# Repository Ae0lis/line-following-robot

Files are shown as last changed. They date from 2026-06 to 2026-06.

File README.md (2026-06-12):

# Autonomous Line-Following Robot

A custom-PCB line-following robot built for the EE 201 capstone at the University
of Washington. This was a one-month competition to design the fastest,
most accurate line follower in the class.

**Full writeup:** https://ae0lis.github.io/projects/line_robot/

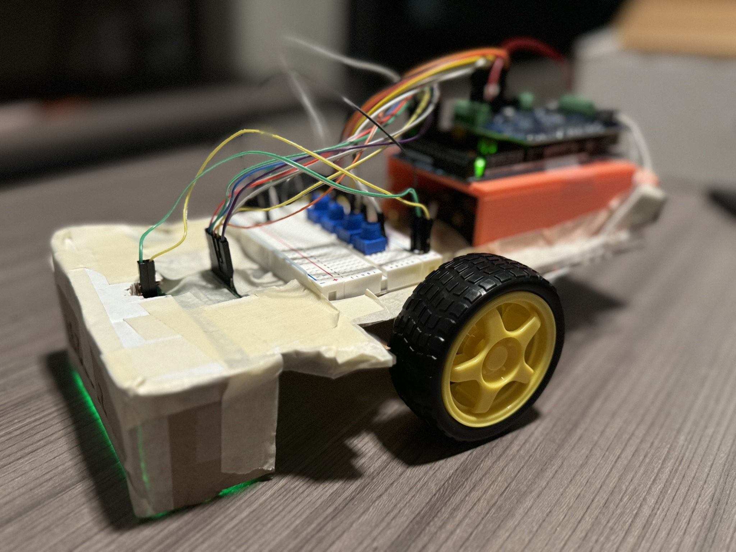
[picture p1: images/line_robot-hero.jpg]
The finished robot


## Overview

The robot follows a black line on a light surface using a custom seven-channel
photoresistor array, processes the readings through a PID controller on an Arduino,
and steers by driving its two motors at differing speeds. Built by a three-person
team over one month; completed the full competition track.

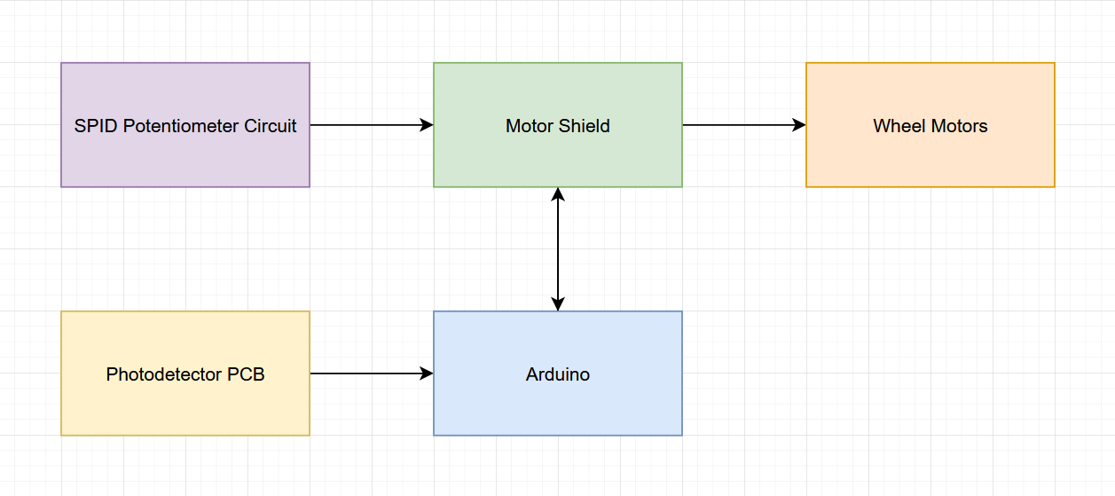
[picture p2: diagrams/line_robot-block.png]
Block diagram


## Repository structure

| Path | Contents |
|---|---|
| `kicad/` | KiCad project — schematic, board layout, and netlist for the sensor array |
| `kicad/PCB_share/` | Gerber + drill files for fabrication (open in any Gerber viewer, no KiCad needed) |
| `firmware/` | Arduino control code (see note below) |
| `renders/` | Exported schematic and 3D board renders |
| `images/` | Photos of the assembled robot |
| `diagrams/` | Diagrams for explaining the robot's systems |

## The sensor board

The core of the project is a custom PCB I designed and laid out in KiCad:

- **Seven-channel photoresistor array** — each channel pairs a photoresistor with an
  LED, flooding the surface with consistent light so a change in reading reflects
  floor color rather than ambient light or shadow.
- **Per-LED current limiting** — each LED has its own 1 kΩ resistor.
- **Copper pours** for GND and VCC instead of hand-routed power traces, which helped
  keep the board compact (40 × 80 mm between mounting holes).
- **Sensor outputs map to Arduino analog pins A8–A14**, matching the firmware.

## Firmware

The control firmware is based on PID scaffolding provided to all teams in the course.
My contribution here was mapping the controller to this board's pin assignments,
configuring it, and tuning the PID constants against the competition track. Both
files are included for transparency:

- `10_5_line_follower_code_template.ino` — the course-provided starting point
- `10_5_line_follower_code_completed.ino` — the filled-in, tuned version used in the robot

Tuned constants at competition: S 30, P 24, I 0, D 24.
Calibrated sensor readings: ~2500 on black, ~1000 on white.

## Viewing the board

- **Renders:** the PNGs in `renders/` show the schematic and 3D board.
- **Gerbers:** open `kicad/PCB_share/` in any Gerber viewer to inspect the manufacturing layers.
- **Source:** open `kicad/Final_Project_PCB.kicad_pro` in KiCad 9.0 or newer. 
			  May work on older versions, but no promises!

## Team

Built by Dat Ly, Michael Zhang, and Ben Robison for EE 201 (University of Washington).
I (Ben) was responsible for the sensor PCB, firmware configuration and tuning, and much of
the physical assembly.

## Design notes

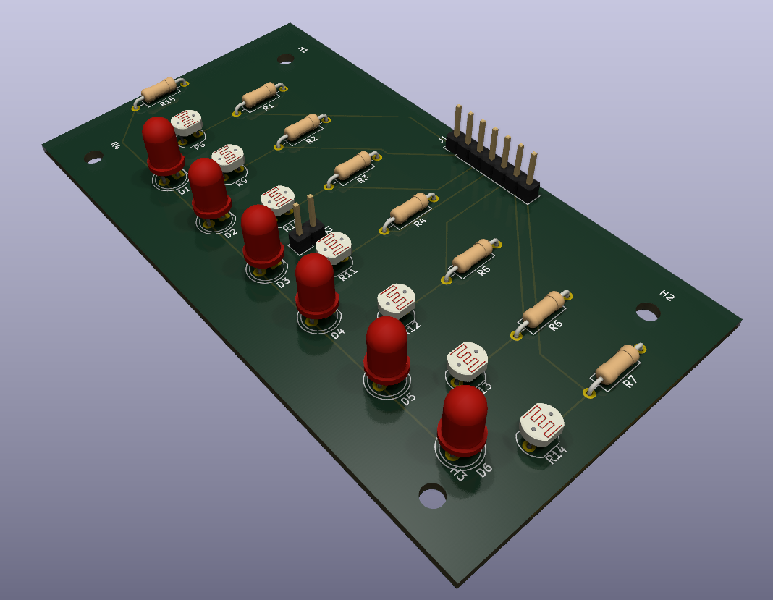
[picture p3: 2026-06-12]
renders/line_robot-pcb.png

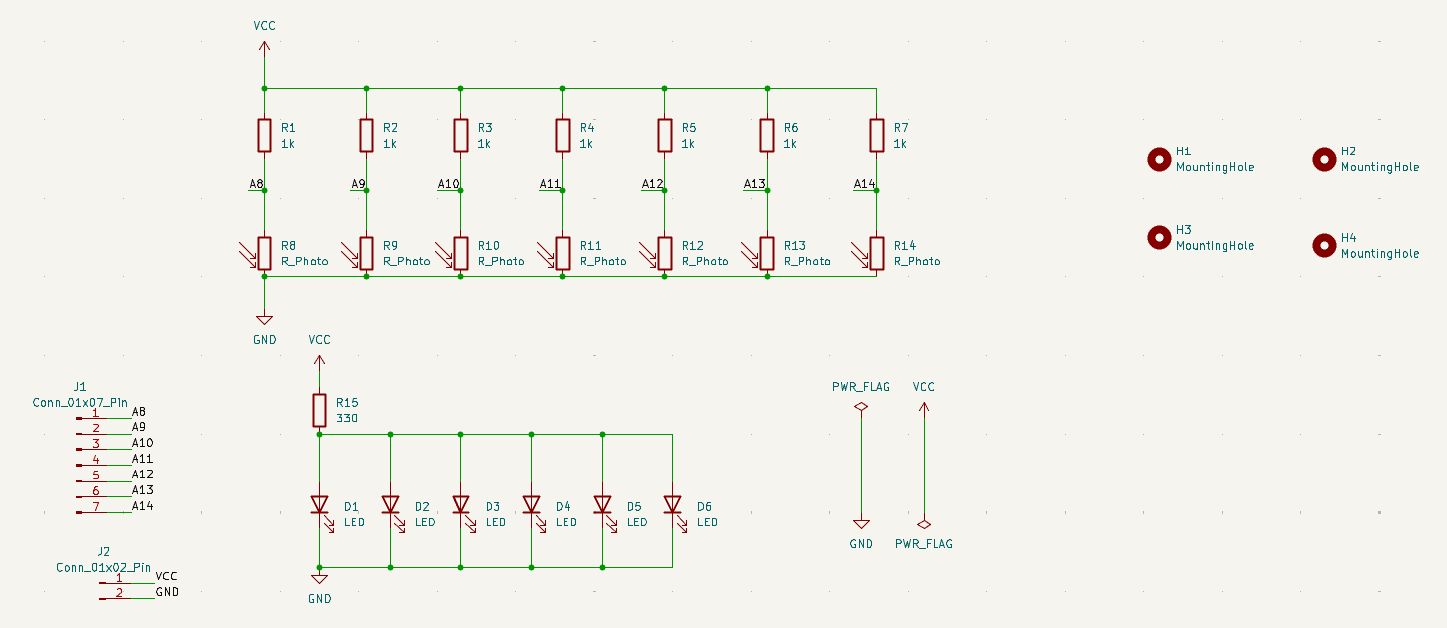
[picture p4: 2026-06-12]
renders/line_robot-sch.png

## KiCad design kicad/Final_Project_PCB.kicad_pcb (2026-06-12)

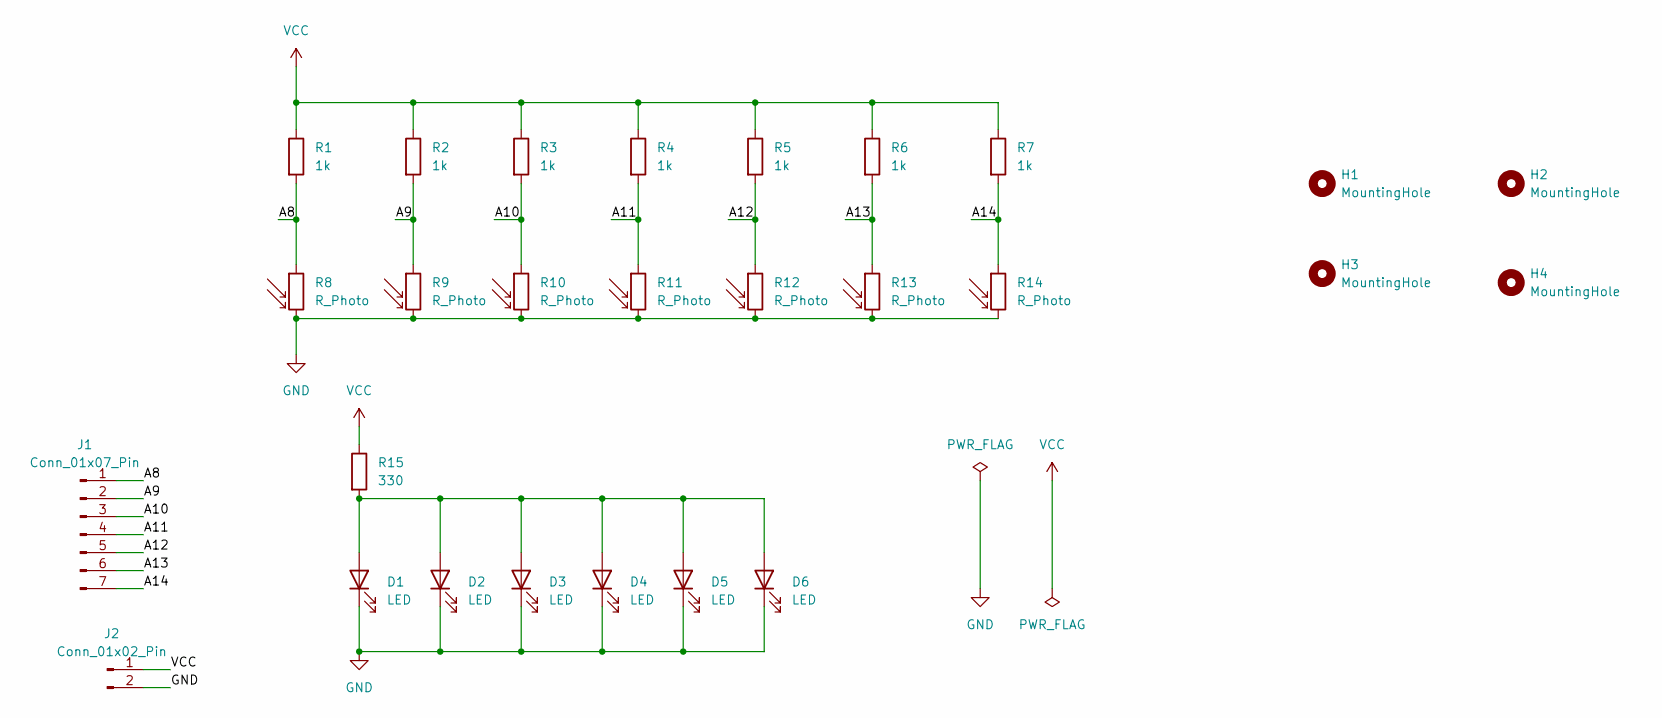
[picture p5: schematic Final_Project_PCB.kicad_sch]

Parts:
D1, D2, D3, D4, D5, D6: LED; LED_D5.0mm
H1, H2, H3, H4: MountingHole; MountingHole_3.2mm_M3
J1: Conn_01x07_Pin; PinHeader_1x07_P2.54mm_Vertical
J2: Conn_01x02_Pin; PinHeader_1x02_P2.54mm_Vertical
R1, R2, R3, R4, R5, R6, R7: 1k; R_Axial_DIN0207_L6.3mm_D2.5mm_P10.16mm_Horizontal
R8, R9, R10, R11, R12, R13, R14: R_Photo; R_LDR_5.0x4.1mm_P3mm_Vertical
R15: 330; R_Axial_DIN0207_L6.3mm_D2.5mm_P10.16mm_Horizontal

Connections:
/A8: J1.1, R1.2, R8.1
/A9: J1.2, R2.2, R9.1
/A10: J1.3, R3.2, R10.1
/A11: J1.4, R4.2, R11.1
/A12: J1.5, R5.2, R12.1
/A13: J1.6, R6.2, R13.1
/A14: J1.7, R7.2, R14.1
GND: D1.1 (K), D2.1 (K), D3.1 (K), D4.1 (K), D5.1 (K), D6.1 (K), J2.2, R8.2, R9.2, R10.2, R11.2, R12.2, R13.2, R14.2
unnamed: D1.2 (A), D2.2 (A), D3.2 (A), D4.2 (A), D5.2 (A), D6.2 (A), R15.2
VCC: J2.1, R1.1, R2.1, R3.1, R4.1, R5.1, R6.1, R7.1, R15.1

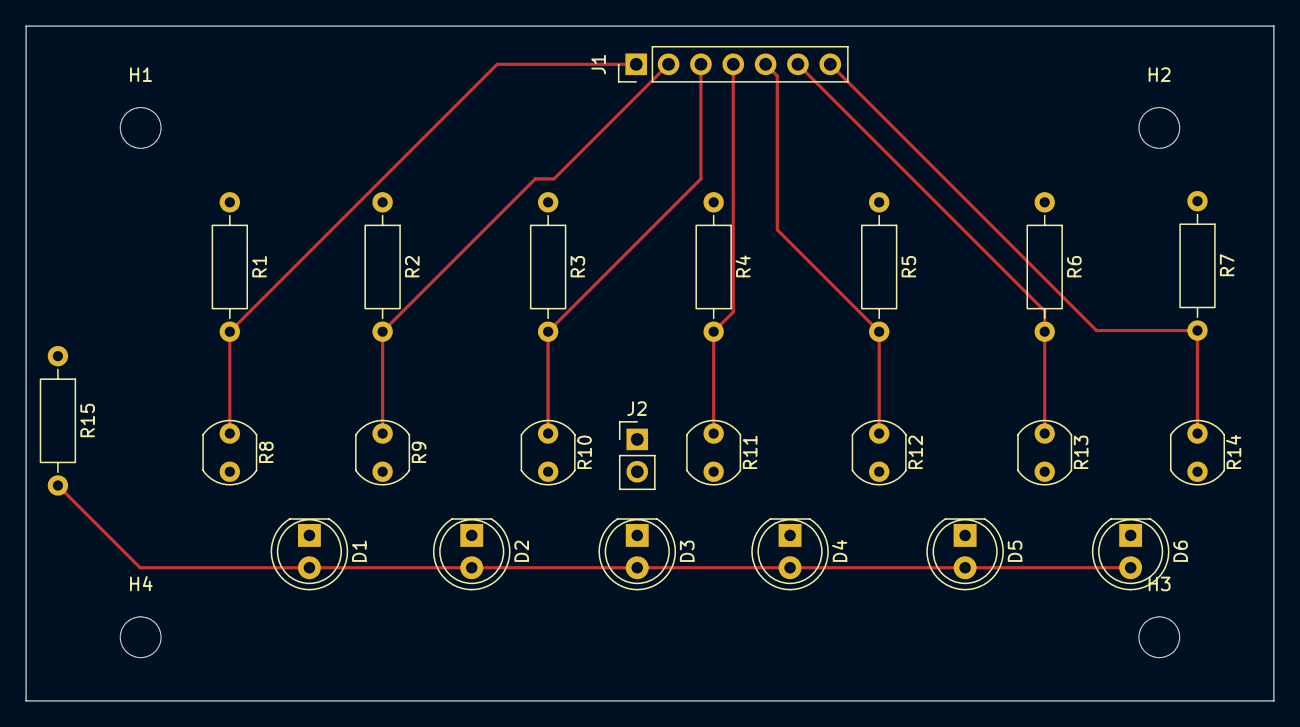
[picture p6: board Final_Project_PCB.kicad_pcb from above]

Board: 2 copper layers, 98.0 x 53.0 mm, 27 parts (0 on the bottom side), 10 nets.

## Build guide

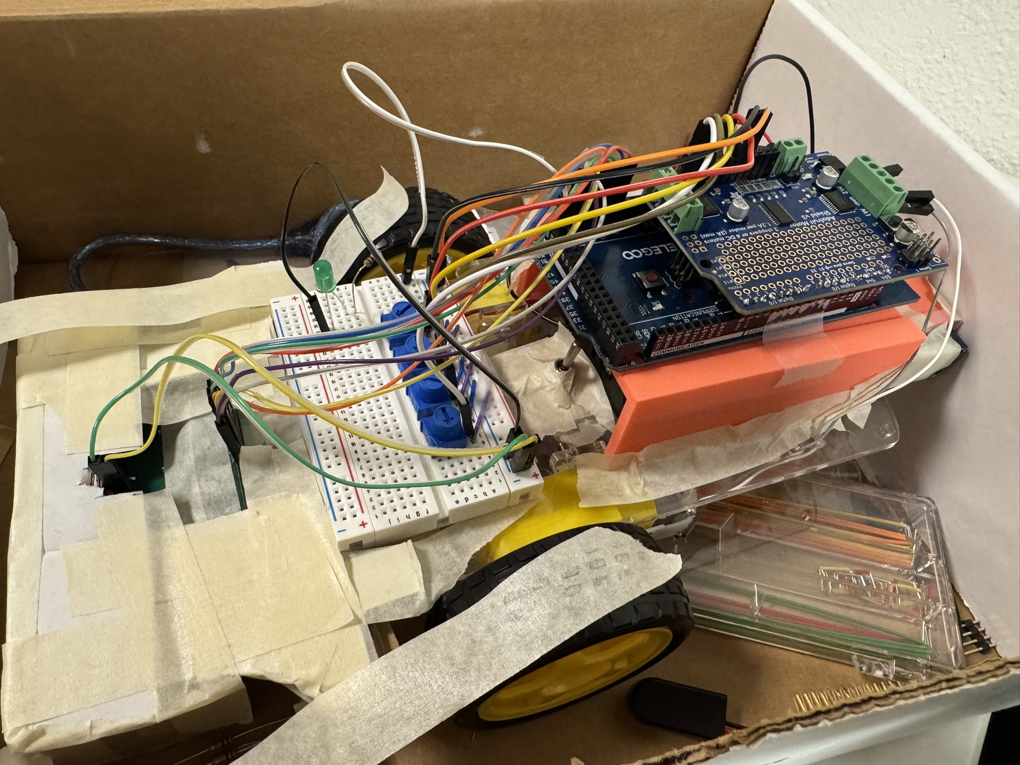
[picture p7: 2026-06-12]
images/line_robot-assembly.jpg

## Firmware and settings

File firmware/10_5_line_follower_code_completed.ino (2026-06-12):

/* ************************************************************************************************* */
// * ECE 201: Line Following Robot with PID * //
/* ************************************************************************************************* */
// This is code for your PID controlled line following robot. 
//
// Code Table of Contents
  // 1) Declare Variables - declares many variables as global variables so each variable can be accessed from every function
  // 2) Setup (Main) - runs once at beginning when you press button on arduino or motor drive or when you open serial monitor
  // 3) Loop (Main) - loops forever calling on a series of functions 
  // 4) Blink - blinks and LED
  // 5) Calibration - makes white = 0 and black = 100 (a few seconds to prep, a few seconds on white, a few seconds to move to black, a few seconds of black)
  // 6) Read Potentiometers - reads each potentiometer
  // 7) Run Motors - runs motors
  // 8) Read Photoresistors - reads each photoresistor
  // 9) Calculate Error - calculate error from photoresistor readings
  // 10) PID Turn - takes the error and implements PID control
  // 11) Print - used for debugging but can comment out when not debugging because it slows down program

// ************************************************************************************************* //
// Declare Variables

// Variables and Libaries for Motor
#include <Wire.h>
#include <Adafruit_MotorShield.h> // Must add libary - see MotorShield Manual
//https://cdn-learn.adafruit.com/downloads/pdf/adafruit-motor-shield-v2-for-arduino.pdf

Adafruit_MotorShield AFMS = Adafruit_MotorShield();
// Motors can be switched here (1) <--> (2)
Adafruit_DCMotor *Motor1 = AFMS.getMotor(1); // left motor
Adafruit_DCMotor *Motor2 = AFMS.getMotor(2); // right motor
  
// Set Initial Speed of Motors (CAN BE EDITED BY USER)
// TODO: Replace "___", and set the default motor speeds to an integer between 0 and 255.
//  the defualt motor speed is how fast the cart will move with no inputs. this can be
//  thought of as how fast should the cart be going when travelling in a straight line.
//  theoretical max. is 255, but the motors will likely overdraw power and cause the Arduino to shut off. 
//  motors likely need a minimum speed of at least 30 to move the cart.
//  a good starting speed is roughly 50-60. motor speeds are separated incase one motor turns faster than the other.  
const int M1Sp = ___; 
const int M2Sp = ___;

// Variables for Potentiometer
// TODO: Replace "___", and assign the pin number connected to the Arduino
const int S_pin = ___; //proportional control
const int P_pin = ___; //proportional control
const int I_pin = ___; //integral control
const int D_pin = ___; //derivative control

// User set SPID values
// TODO: Replace "___", and assign an integer value for the MAX value of S, P, I, and D.
//  The on-cart potentiometers are used to determine the actual values of S, P, I, and D. 
//  Note: These values will likely need to be experimentally determined
const float speed       = ___;
const float proportion  = ___;
const float integral    = ___;
const float derivative  = ___;

const int numMeas = ___; // TODO: Replace "___", and assign number of calibration measurements
                         //   setting numMeas to 40 as in code 10.4 is recommended

// Initialize SPID values to zero
int SpRead = 0; //Speed Increase 
int kPRead = 0; //proportional gain
int kIRead = 0; //integral gain
int kDRead = 0; //derivative gain
  
// Variables for Light Sensors (arrays are used to simplify the code):
//  these are variables that have multiple elements to each variable name.
//  LDR_Pin holds 7 values of the LDR pin connection to the Arduino
// TODO: Replace "___", and assign the pin number for each LDR connected to the Arduino.
//  reference 10.2 potentiometer code if necessarry
int LDR_Pin[7] = {___,
                  ___,
                  ___,
                  ___,
                  ___,
                  ___,
                  ___}; 
int LDR[7]; // this is an empty array that will hold the readings from our potentiometers

// TODO: Replace "___", and assign the pin number connected to the Arduino.
//  it is recommended to use the built-in LED connected to pin 13, but can change 
//  to another digital pin and connect external LED to be more easily seen
int led_Pin = ___; 

// Calibration Variables
//  Complete understanding of the calibration process is not required 
float Mn[7]; // array containing minimum read values of every potentiometer
float Mx[7]; // array containing maximum read values of every potentiometer
float LDRf[7] = {0.,0.,0.,0.,0.,0.,0.}; // initialize the LDR read values to float zero

int MxRead; // maximum read value by any potentiometer
int MxIndex; // index (location in array) of max read value
float AveRead; // average read value of potentiometer
int CriteriaForMax; // value to determine whether a read value is a max
float WeightedAve; // weighted average after calibration
  
// Error calculation variables
int im0, im1, im2; 
  
// Motor control variables
int M1SpeedtoMotor, M2SpeedtoMotor; // actual speeds motor will be rotating at
int Turn; // which direction and how sharply should the cart turn
int M1P = 0, M2P = 0; // proportion control for motors 1 and 2 respectively
float error; // current error
int lasterror = 0; // previous error
int sumerror = 0; // sum of total errors
float kP, kI, kD; // final values of P, I, and D used in control
 
// ************************************************************************************************* //
// setup - runs once
void setup() {
  Serial.begin(___); // TODO: Replace "___", and input the baud rate for serial communication
  AFMS.begin(); // initialize the motor

  pinMode(___, ___); // TODO: Replace "___", and set the led_pin to be an output
  
  Calibrate(); // Calibrate black and white sensing
  
  ReadPotentiometers(); // Read potentiometer values (Sp, P, I, & D)
  
  delay(2000); // Delay to ensure cart is properly placed before moving
  
  RunMotors(); // Starts motors straight forward depending on Sp (Speed from potentiometer) and M1Sp/M2Sp (Nominal values)
 
} // end setup()

// ************************************************************************************************* //
// loop - runs/loops forever
void loop() {
  // Note: some functions are only helpful for debugging and can be commented out once functionality is ensured
 
  ReadPotentiometers(); // Only if you want to see Potentiometers working in set up as you run the line following
  
  ReadPhotoResistors(); // Read photoresistors and map to 0-100 based on calibration
  
  CalcError();
  
  PID_Turn(); // PID Control and Output to motors to turn
  RunMotors(); // Uses info from
  
  Print(); // Print values to serial monitor //currently commented out but could be good for debugging =)
 
} // end loop()

// ************************************************************************************************* //
// function to quickly blink an LED
void fastBlink() {
  digitalWrite(___, ___); // TODO: Replace "___", and turn on the LED
  delay(100); // wait for 100 milliseconds

  digitalWrite(___, ___); // TODO: Replace "___", and turn off the LED
  delay(100); // wait for 100 milliseconds
} // end fastBlink()

// ************************************************************************************************* //
// function to slowly blink an LED
void slowBlink() {
  digitalWrite(___, ___); // TODO: Replace "___", and turn on the LED
  delay(100); // wait for 100 milliseconds

  digitalWrite(___, ___); // TODO: Replace "___", and turn off the LED
  delay(900); // wait for 900 milliseconds
} // end slowBlink()

// ************************************************************************************************* //
// function to calibrate
void Calibrate() { 
  // wait to make sure cart is in position with sensors over a white (light) surface
  for (int calii = 0; calii < 4; calii++) { // wait four blinks for the cart to be positioned
    slowBlink(); // blink the indicator LED
  }
  
  // Calibration
  // White Calibration
  for (int calii = ___; calii < ___; calii = ___) { // TODO: Replace "___", and repeat the section of code
                                                    //  for the number of calibration measurements desired

    fastBlink(); // blink the indicator LED

    for (int ci = ___; ci < ___; ci = ____) { // TODO: Replace "___", and loop over all of the LDRs
      LDRf[ci] = LDRf[ci] + (float) analogRead(LDR_Pin[ci]); // keep track of the sum of each LDR's readings
      delay(2); 
    } 
  } 
    
  // Find average of each LDR's read values
  for (int cm = ___; cm < ___; cm = ___) { // TODO: Replace "___", and loop over all of the LDRs
    Mn[cm] = round(LDRf[cm] / (float)numMeas); // take average of each LDR's readings
    LDRf[cm] = 0.; // reset the array holding the sum of the LDR's readings
  }
 
 // Wait to move from White to Black Surface
  for (int calii = 0; calii < 10; calii++) { // wait ten blinks for the cart to be repositioned
    slowBlink();
  }
 
  // Black Calibration
  for (int calii = ___; calii < ___; calii = ___) { // TODO: Replace "___", and repeat the section of code
                                                    //  for the number of calibration measurements desired

    fastBlink(); // blink the indicator LED

    for (int ci = ___; ci < ___; ci = ____) { // TODO: Replace "___", and loop over all of the LDRs
      LDRf[ci] = LDRf[ci] + (float) analogRead(LDR_Pin[ci]); // keep track of the sum of each LDR's readings
      delay(2); 
    } 
  }  
  
  // Find average of each LDR's read values
  for (int cm = ___; cm < ___; cm = ___) { // TODO: Replace "___", and loop over all of the LDRs
    Mx[cm] = round(LDRf[cm] / (float)numMeas); // take average of each LDR's readings
    LDRf[cm] = 0.; // reset the array holding the sum of the LDR's readings
  }
} // end Calibrate()

// ************************************************************************************************* //
// function to read and map values from potentiometers
void ReadPotentiometers() {
  SpRead = map(analogRead(S_pin), 0, 1023, 0, speed);
  kPRead = map(analogRead(P_pin), 0, 1023, 0, proportion);
  kIRead = map(analogRead(I_pin), 0, 1023, 0, integral);
  kDRead = map(analogRead(D_pin), 0, 1023, 0, derivative);
} // end ReadPotentiometers()
 
// ************************************************************************************************* //
// function to start motors using nominal speed + speed addition from potentiometer
void RunMotors() { 
  M1SpeedtoMotor = min(M1Sp + SpRead + M1P, 255); // limits speed to 255 
  M2SpeedtoMotor = min(M2Sp + SpRead + M2P, 255); // remember M1Sp & M2Sp is defined at beginning of code (default 60)
  
  Motor1->setSpeed(abs(M1SpeedtoMotor)); 
  Motor2->setSpeed(abs(M2SpeedtoMotor));
  
  // Motor 1 control
  if (M1SpeedtoMotor > 0) {
    Motor1->run(FORWARD);
  } else { // < 0
    Motor1->run(BACKWARD);
  }

  // Motor 2 control
  if (M2SpeedtoMotor > 0) {
    Motor2->run(FORWARD);
  } else { // < 0 
    Motor2->run(BACKWARD);
  }
} // end RunMotors()

// ************************************************************************************************* //
// function to read photo resistors, map from 0 to 100, and find darkest photo resitor (MxIndex)
void ReadPhotoResistors() {
  for (int Li = ___; Li < ___; Li = ___) { // TODO: Replace "___", and loop over all of the LDRs
    LDR[Li] = map(analogRead(LDR_Pin[Li]), Mn[Li], Mx[Li], 0, 100);
    delay(2); 
  }
} // end ReadPhotoResistors()

// ************************************************************************************************* //
// Calculate error from photoresistor readings
//  Do not worry about understanding or completing this function
void CalcError() {
  MxRead = -99; // initialize max read to an impossible value to ensure initialization does not impact functionality
  AveRead = 0.0; // initialize the average read

  for (int i = 0; i < 7; i = i + 1) { // loop over all of the LDRs
    if (MxRead < LDR[i]) { // if LDR value is greater than current max
      MxRead = LDR[i]; // set max equal to LDR value
      MxIndex = -1 * (i-3);
      im1 = (float)i;
    }
    AveRead = AveRead + (float)LDR[i]/7.;
  } 
  CriteriaForMax = 2; // max should be at least twice as big as the other values 
  if (MxRead > CriteriaForMax*AveRead) {
    if (im1 != 0 && im1 != 6) {
      im0 = im1 - 1;
      im2 = im1 + 1;
      WeightedAve = ((float)(LDR[im0] * im0 + LDR[im1]*im1 + LDR[im2] * im2))/((float)(LDR[im0] + LDR[im1] + LDR[im2]));
      error = -1 * (WeightedAve - 3);
    }
    else if (im1 == 0) {
      im2 = im1 + 1;
      WeightedAve = ((float)(LDR[im1]*im1 + LDR[im2]*im2))/((float)(LDR[im1]+LDR[im2]));
      error = -1 * (WeightedAve - 3);
    }
    else if (im1 == 6) {
      im0 = im1 - 1;
      WeightedAve = ((float)(LDR[im0]*im0 + LDR[im1]*im1))/((float)(LDR[im0]+LDR[im1]));
      error = -1 * (WeightedAve - 3);
    } 
  } 

  if (isnan(error)) {
    error = lasterror;
  } else {
    error = error;
  }
} // end CalcError()

// ************************************************************************************************* //
// function to make a turn (a basic P controller)
void PID_Turn() {
  // Read values are scaled PID constants from potentiometers
  kP = (float)kPRead; 
  kI = (float)kIRead; 
  kD = (float)kDRead;

  // error holds values from -3 to 3
  Turn = error * kP + sumerror * kI + (error - lasterror) * kD; //PID!!!!!
  
  sumerror = sumerror + error;

  // prevents integrator wind-up
  if (sumerror > 5) {
    sumerror = 5; 
  } else if (sumerror < -5) {
    sumerror = -5;
  }
  
  lasterror = error;
  
  // One motor becomes slower and the other faster, to "turn"
  if (Turn < 0) { // turn in direction of M2
    M1P = Turn; 
    M2P = -Turn;
  } else if (Turn > 0) { // turn in direction of M1
    M1P = Turn; 
    M2P = -Turn;
  } else { // continue in straight line
    M1P = 0; 
    M2P = 0;
  } 
} // end PID_Turn()

// ************************************************************************************************* //
// function to print values of interest
void Print() {
  Serial.print(Turn); Serial.print(" ");
  Serial.print(error); Serial.print(" ");
  Serial.print(sumerror); Serial.print(" ");
  Serial.print(lasterror); Serial.print(" ");
  
  Serial.print("   |   "); // create a visual divider
  
  Serial.print(SpRead); Serial.print(" "); // Initial Speed addition from potentiometer
  Serial.print(kP); Serial.print(" "); // PID values from potentiometers after scaling 
  Serial.print(kI); Serial.print(" ");
  Serial.print(kD); Serial.print(" ");

  Serial.print("   |   "); // create a visual divider
  
  Serial.print(LDR[0]); Serial.print(" "); // Each photo resistor value is shown
  Serial.print(LDR[1]); Serial.print(" ");
  Serial.print(LDR[2]); Serial.print(" ");
  Serial.print(LDR[3]); Serial.print(" ");
  Serial.print(LDR[4]); Serial.print(" ");
  Serial.print(LDR[5]); Serial.print(" ");
  Serial.print(LDR[6]); Serial.print(" "); 

  Serial.print("   |   "); // create a visual divider
  
  Serial.print(MxRead); Serial.print(" "); // the maximum value from the photo resistors is shown again
  Serial.print(MxIndex);Serial.print(" "); // this is the index of that maximum (0 through 6) (aka which element in LDR)
  Serial.print(error); Serial.print(" "); // this will show the calculated error (-3 through 3) 

  Serial.print("   |   "); // create a visual divider
  
  Serial.print(M1SpeedtoMotor); Serial.print(" "); // This prints the arduino output to each motor so you can see what the values (0-255)
  Serial.println(M2SpeedtoMotor); // that are sent to the motors would be without actually needing to power/run the motors
  
  delay(200); //just here to slow down the output for easier reading if wanted 
                 // ensure delay is commented when actually running your robot or this will slow down sampling too much
                 // and prevent the cart from functioning well
} // end Print()
